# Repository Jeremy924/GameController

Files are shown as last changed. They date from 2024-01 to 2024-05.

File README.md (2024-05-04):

# Game Controller
User inputs are inputted into the arduino from two joysticks and four buttons. The arduino then sends the data to the computer through the serial port. 
The computer can also send a command to the arduino to set the color of an RGB LED. 

## Files
### GameController.py
The GameController class represents the game controller. The game controller class contains a
generator called start_input() that yields ControllerInput objects. The ControllerInput class represents the current
state of the controller inputs. The inputs are stored in a dictionary. The ControllerInput class
also has a dictionary containing only the inputs that have changed since last input. 

### KeyMapper.py
The KeyMapper class is used to simulate keyboard inputs based on user input from the game
controller. The KeyMapper class uses a dictionary from a json file to store the key
bindings. 

## PCB Design
Originally, a permanant breadboard was used, but the controller was switched to a PCB to make it sturdier. 
PCB Design

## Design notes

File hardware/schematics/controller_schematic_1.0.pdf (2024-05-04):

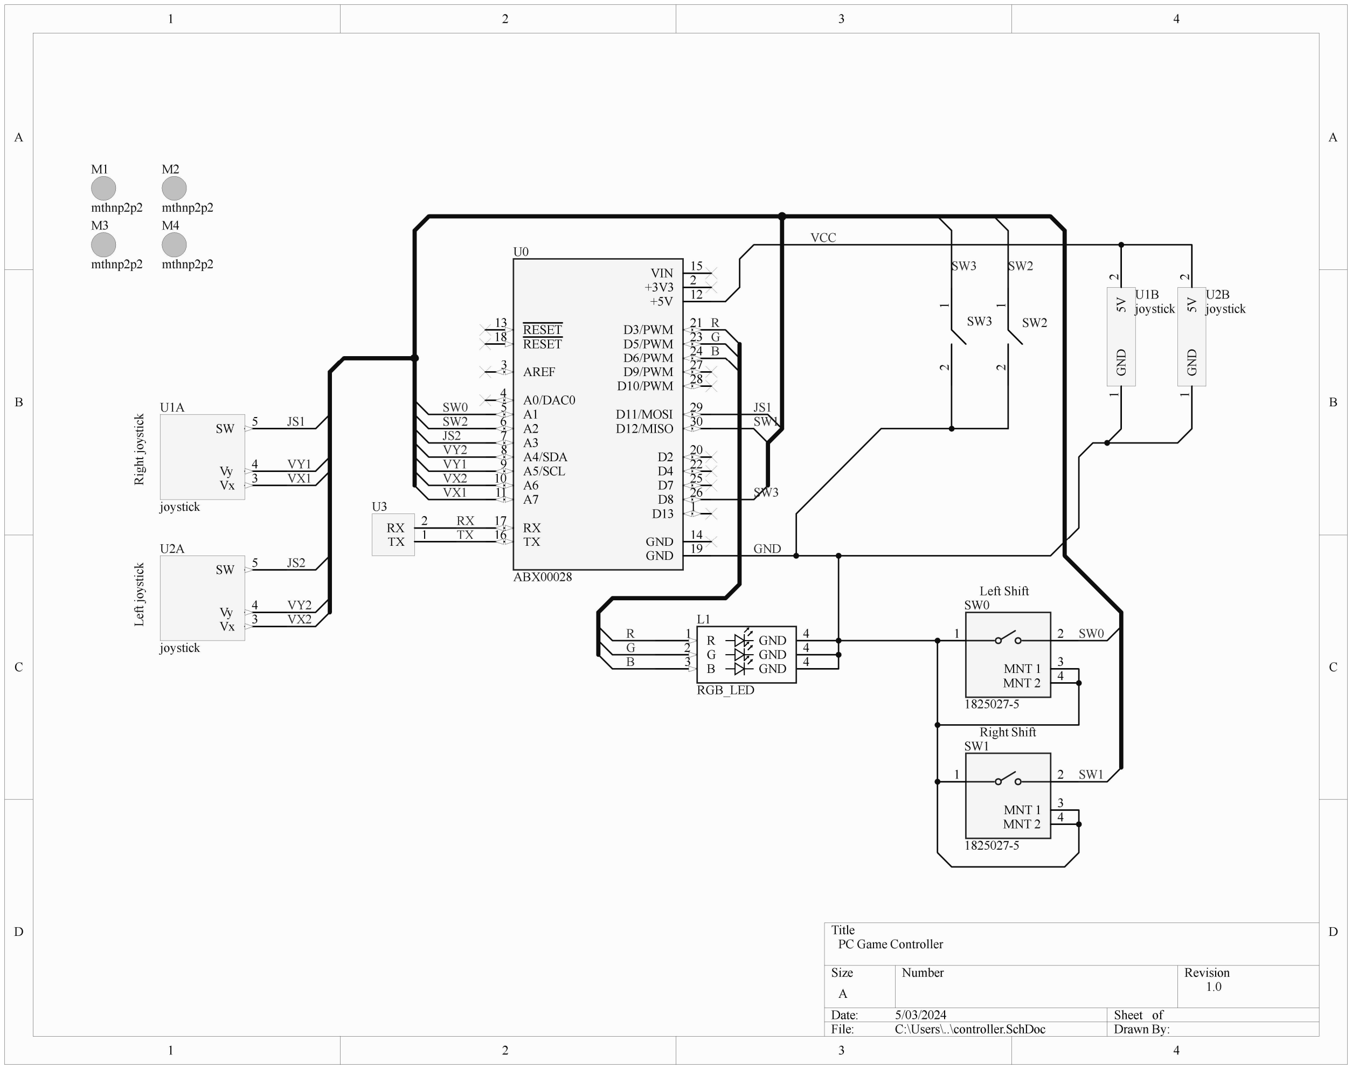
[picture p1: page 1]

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
Title

Size | Number | Revision
A
Date: | 5/03/2024 | Sheet of
File: | C:\Users\..\controller.SchDoc | Drawn By:

RESET 13
RESET 18

AREF 3

A0/DAC0 4
A1 5
A2 6
A3 7
A4/SDA 8
A5/SCL 9
A6 10
A7 11

RX 17
TX 16

VIN 15
+3V3 2
+5V 12

D3/PWM 21
D5/PWM 23
D6/PWM 24
D9/PWM 27
D10/PWM 28

D11/MOSI 29
D12/MISO 30

D2 20
D4 22
D7 25
D8 26
D13 1

GND 14
GND 19

U0

ABX00028

SW1

Right Shift

Left Shift Right joystick Left joystick

PC Game Controller

1.0

Vx 3

Vy 4

SW 5

U1A

joystick | 5V

## 2 GND

1

U1B
joystick

Vx 3

Vy 4

SW 5

U2A

joystick | 5V

## 2 GND

1

U2B
joystick
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
GND 4

GND 4

GND 4

L1

RGB_LED

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
SW3 SW2

JS1
SW1

SW3

GND

VCC

RX 2
TX 1

U3
RX
TX

1 2

SW2 ¹ 2
SW3

1 2

MNT 1 3
MNT 2 4

SW0

1825027-5

1 2

MNT 1 3
MNT 2 4

SW1

1825027-5

SW0

M1

mthnp2p2

M2

mthnp2p2
M3

mthnp2p2

M4

mthnp2p2

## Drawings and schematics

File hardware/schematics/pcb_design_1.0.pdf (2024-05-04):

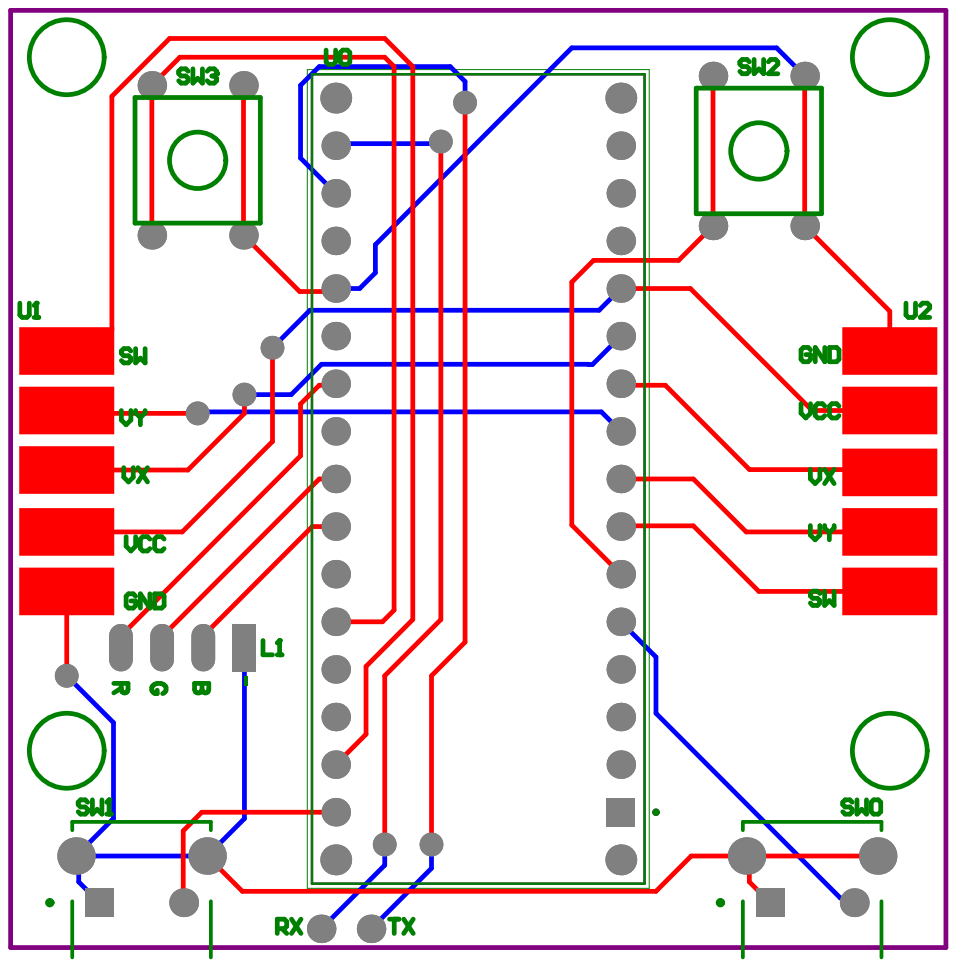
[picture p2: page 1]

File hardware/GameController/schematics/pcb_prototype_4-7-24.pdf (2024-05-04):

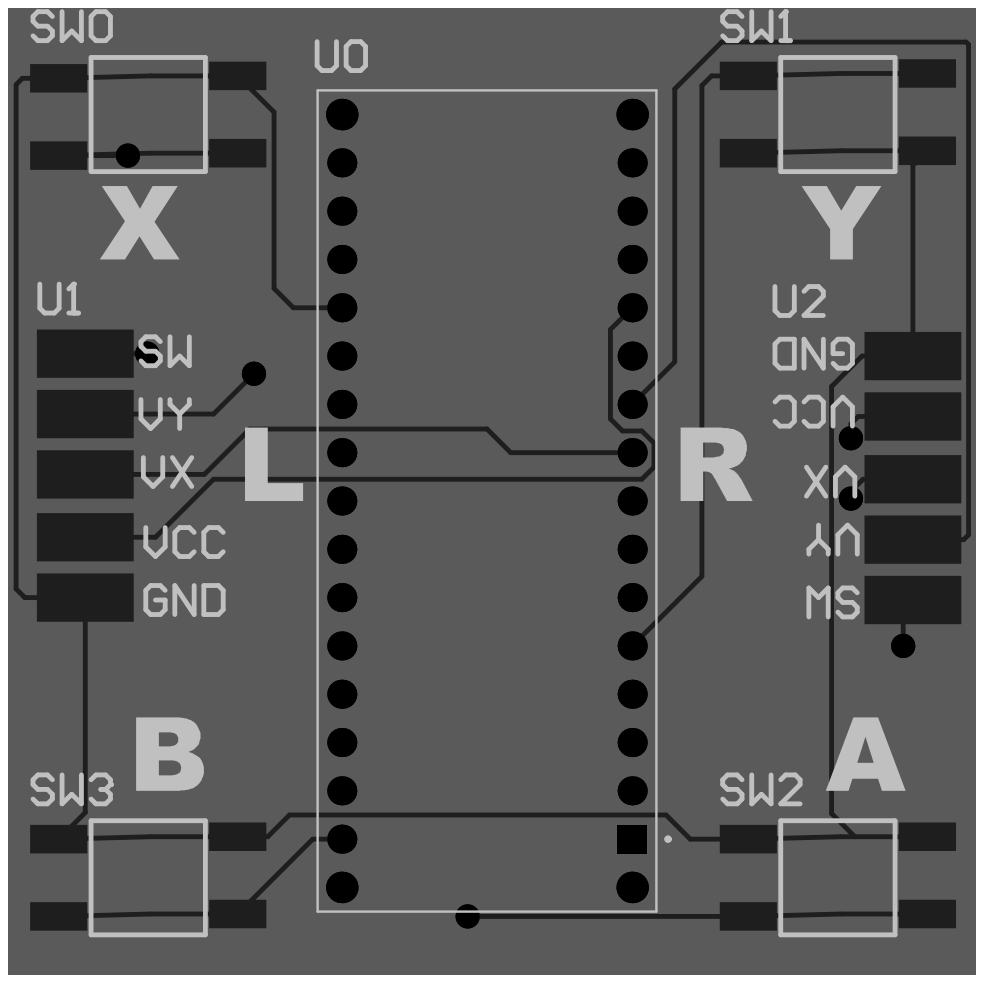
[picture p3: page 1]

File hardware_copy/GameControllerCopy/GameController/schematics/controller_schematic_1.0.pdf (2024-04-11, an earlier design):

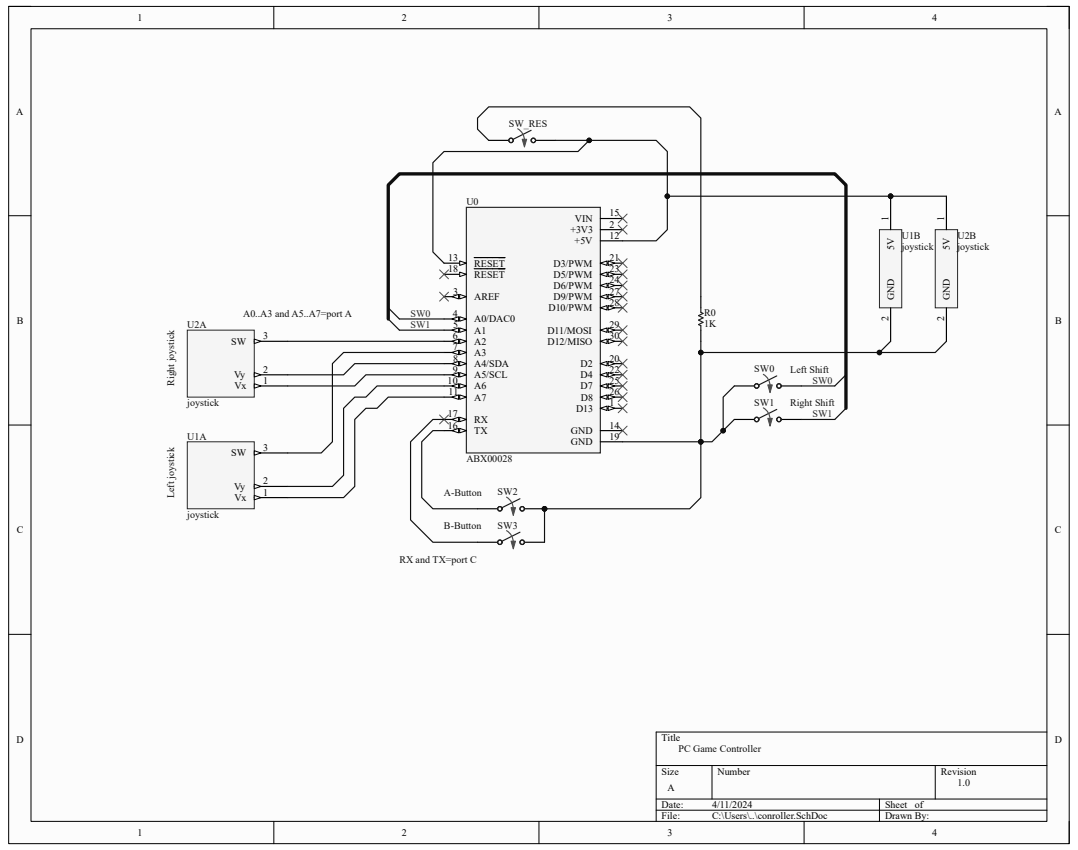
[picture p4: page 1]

joystick Right joystick Left joystick

RX and TX=port C

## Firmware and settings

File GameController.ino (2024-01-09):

#define RIGHT_BUTTON 6
#define LEFT_BUTTON 19

#define RIGHT_VRX A0
#define RIGHT_VRY A1
#define LEFT_VRX A2
#define LEFT_VRY A3

#define LEFT_JS_BUTTON A4
#define RIGHT_JS_BUTTON 4


#define RED 3
#define GREEN 9
#define BLUE 10

#define NUM_SENSORS 8

int lastVals[NUM_SENSORS] = { 0 };

bool isConnected = false;

void setup() {
  // put your setup code here, to run once:
  pinMode(LEFT_BUTTON, INPUT_PULLUP);
  pinMode(RIGHT_BUTTON, INPUT_PULLUP);
  pinMode(LEFT_JS_BUTTON, INPUT_PULLUP);
  pinMode(RIGHT_JS_BUTTON, INPUT_PULLUP);

  pinMode(RIGHT_VRX, INPUT);
  pinMode(LEFT_VRX, INPUT);

  pinMode(RIGHT_VRY, INPUT);
  pinMode(LEFT_VRY, INPUT);

  pinMode(RED, OUTPUT);
  pinMode(GREEN, OUTPUT);
  pinMode(BLUE, OUTPUT);

  Serial.begin(1000000);

  connect();
}

void connect() {
  if (isConnected) {
    return;
  }

  int count = 0;
  int colorVal = 10;
  bool forward = true;
  String s;
  do {
    while (!Serial.available()) {
    if (count % 50 == 0) if (forward) colorVal++; else colorVal--;
    if (forward) count++; else count--;
    if (count == 2000 || count == 0) forward = !forward;
    setLED(colorVal * 4, colorVal / 4, 0);
    delayMicroseconds(300);
    }
    s = Serial.readStringUntil('\n');
    

  } while (!s.equals("ready"));

  Serial.println("OK");

  while (Serial.available()) {
    Serial.read();
  }
  

  analogWrite(RED, 0);
  analogWrite(GREEN, 0);
  isConnected = true;
}

void setLED(byte red, byte green, byte blue) {
  if (red > 100) red = 100;
  if (green > 100) green = 100;
  if (blue > 100) blue = 100;
  analogWrite(RED, red);
  analogWrite(GREEN, green);
  analogWrite(BLUE, blue);
}

void checkForCommand() {
  if (Serial.available()) {
    String s = Serial.readStringUntil('\n');
    if (s == "LED") {
      while (!Serial.available()) continue;
      byte colors[3];
      Serial.readBytes(colors, 3);
      setLED(colors[0], colors[1], colors[2]);
    }
  }
}


void printState(int* values, int size) {
  checkForCommand();
  for (int i = 0; i < size; i++) {
    if (i < 2 || i == 4 || i == 5)
      Serial.println(values[i] >> 2);
    else
      Serial.println(values[i]);
  }

  Serial.println();
}


void outState(int* values, int size) {
  checkForCommand();
  Serial.write((byte) (values[0] >> 2)); // LEFT VRX
  Serial.write((byte) (values[1] >> 2)); // LEFT VRY
  Serial.write((byte) (values[4] >> 2)); // RIGHT VRX
  Serial.write((byte) (values[5] >> 2)); // RIGHT VRY

  //                       LEFT_BUTTON   LEFT_JS_BUTTON      RIGHT_BUTTON       RIGHT_JS_BUTTON
  byte combined_digitals = (values[2]) + (values[3] << 1) + (values[6] << 2) + (values[7] << 3);
  Serial.write(combined_digitals);
}


void loop() {
  int currentVals[] = { analogRead(LEFT_VRX), analogRead(LEFT_VRY), !digitalRead(LEFT_BUTTON), !digitalRead(LEFT_JS_BUTTON), 
                          analogRead(RIGHT_VRX), analogRead(RIGHT_VRY), !digitalRead(RIGHT_BUTTON), !digitalRead(RIGHT_JS_BUTTON) };

  for (int i = 0; i < NUM_SENSORS; i++) {
    if (currentVals[i] != lastVals[i]) {
      delay(1);
      outState(currentVals, NUM_SENSORS);
      break;
    }
  }

  for (int i = 0; i < NUM_SENSORS; i++) lastVals[i] = currentVals[i];

}

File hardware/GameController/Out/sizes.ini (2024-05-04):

[Page0.emf]
Pixel_PrintingWidth=6000
Pixel_PrintingHeight=4000
Mils_PrintingHeight=4000
Mils_PrintingWidth=6000

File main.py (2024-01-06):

import serial
import keyboard
import time
import sys

s = serial.Serial('COM7', 1_000_000)

gas = 0
brake = 0
turn_angle = 0
last = 502
value = None


def set_color(red, green, blue, port):
    b = bytearray(b'LED\n')
    b.append(red)
    b.append(green)
    b.append(blue)
    port.write(b)
    port.flush()
    time.sleep(0.01)


def unhandled_exception(exc_type, exc_value, exc_traceback):
    set_color(128, 0, 0, s)
    s.flush()
    raise exc_value


sys.excepthook = unhandled_exception


def buffered_read(port, sep=b'\r\n'):
    while True:
        port.write(b'ready\n')
        port.flush()
        time.sleep(0.1)

        if port.in_waiting != 0:
            val = port.read(4)
            if val == b'OK\r\n':
                break

    GAS_FLAG = 0x0002
    BRAKE_FLAG = 0x0001
    SHIFT_UP_FLAG = 0x0004
    SHIFT_DOWN_FLAG = 0x0008
    TURN_FLAG = 0xFFC0
    V_FLAG = 0xFF0000
    V_OFFSET = 16
    TURN_OFFSET = 6

    while True:
        buffer = port.read(3)
        byte_val = list(map(int, list(buffer)))
        value = (byte_val[2] << 16) + (byte_val[0] << 8) + byte_val[1]
        gas = value & GAS_FLAG != 0
        brake = value & BRAKE_FLAG != 0
        shift_up = value & SHIFT_UP_FLAG != 0
        shift_down = value & SHIFT_DOWN_FLAG != 0
        turn = (value & TURN_FLAG) >> TURN_OFFSET
        vertical = (value & V_FLAG) >> V_OFFSET
        yield gas, brake, shift_up, shift_down, (turn - 522), vertical


# 11000001

pulse_count = 0
last_movement = 0
last_shift_change = 0
gas_pressed = False
brake_pressed = False
left_turn_pressed = False
right_turn_pressed = False
shift_down_pressed = False
shift_up_pressed = False

for gas, brake, shift_up, shift_down, turn, vertical in buffered_read(s):
    gas = vertical < 100
    brake = vertical > 140

    if gas:
        if not gas_pressed:
            keyboard.press('w')
            gas_pressed = True
    else:
        if gas_pressed:
            keyboard.release('w')
            gas_pressed = False
    if brake:
        if not brake_pressed:
            keyboard.press('s')
            brake_pressed = True
    else:
        if brake_pressed:
            keyboard.release('s')
            brake_pressed = False

    if shift_up:
        if not shift_up_pressed:
            keyboard.press("'")
            shift_up_pressed = True
    else:
        if shift_up_pressed:
            keyboard.release("'")
            shift_up_pressed = False

    if shift_down:
        if not shift_down_pressed:
            shift_down_pressed = True
            keyboard.press('/')
    else:
        if shift_down_pressed:
            keyboard.release('/')
            shift_down_pressed = False

    if turn < -5:
        right_turn_pressed = False
        if last_movement == 1:
            pulse_count = 0
        last_movement = 2
        keyboard.release('a')
        if pulse_count == 0:
            if not left_turn_pressed:
                keyboard.press('d')
                left_turn_pressed = True
        elif pulse_count == 30:
            if left_turn_pressed:
                keyboard.release('d')
                left_turn_pressed = False
        pulse_count = (pulse_count + 1) % max(1, (50 + turn // 10))
    elif turn > 5:
        left_turn_pressed = False
        if last_movement == 2:
            pulse_count = 0
        last_movement = 1
        keyboard.release('d')
        if pulse_count == 0:
            if not right_turn_pressed:
                keyboard.press('a')
                right_turn_pressed = True
        elif pulse_count == 30:
            if right_turn_pressed:
                keyboard.release('a')
                right_turn_pressed = False
        pulse_count = (pulse_count + 1) % max(1, (50 - turn // 10))
    else:
        keyboard.release('d')
        keyboard.release('a')
        left_turn_pressed = False
        right_turn_pressed = False

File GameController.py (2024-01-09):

import serial
import time
import sys


class GameController:
    current_controller = None

    def __init__(self):
        self.port = serial.Serial('COM7', 1_000_000)
        self.analog_inputs = ['LEFT_VRX', 'LEFT_VRY', 'RIGHT_VRX', 'RIGHT_VRY']

    @classmethod
    def set_current_controller(cls, controller):
        cls.current_controller = controller

    @classmethod
    def get_current_controller(cls):
        return cls.current_controller

    def set_color(self, red, green, blue):
        set_color(red, green, blue, self.port)

    def start_input(self):
        port = self.port
        GameController.current_controller = self
        while True:
            port.write(b'ready\n')
            port.flush()
            time.sleep(0.1)

            if port.in_waiting != 0:
                val = port.read(4)
                if val == b'OK\r\n':
                    break

        LEFT_JS_BUTTON = 0x02
        RIGHT_BUTTON = 0x04
        RIGHT_JS_BUTTON = 0x08
        last_input = None

        while True:
            buffer = port.read(5)
            byte_val = list(map(int, list(buffer)))
            left_vrx = byte_val[0]
            left_vry = byte_val[1]
            right_vrx = byte_val[2]
            right_vry = byte_val[3]
            left_pressed = byte_val[4] & 1 == 1
            right_pressed = byte_val[4] & RIGHT_BUTTON != 0
            left_js_pressed = byte_val[4] & LEFT_JS_BUTTON != 0
            right_js_pressed = byte_val[4] & RIGHT_JS_BUTTON != 0

            last_input = ControllerInput(left_vrx, left_vry, right_vrx, right_vry, left_pressed, right_pressed,
                                         left_js_pressed, right_js_pressed, last_input)
            yield last_input


class ControllerInput:
    def __init__(self, left_vrx, left_vry, right_vrx, right_vry, left_pressed,
                 right_pressed, left_js_pressed, right_js_pressed, last):
        self.inputs = {'LEFT_VRX': left_vrx, 'LEFT_VRY': left_vry, 'RIGHT_VRX': right_vrx, 'RIGHT_VRY': right_vry,
                       'LEFT_BUTTON': left_pressed, 'RIGHT_BUTTON': right_pressed, 'LEFT_JS_BUTTON': left_js_pressed,
                       'RIGHT_JS_BUTTON': right_js_pressed}
        self.analog_inputs = ['LEFT_VRX', 'LEFT_VRY', 'RIGHT_VRX', 'RIGHT_VRY']
        self.last = last
        self.changes = {}
        for key in self.inputs:
            if (last is None or self.inputs[key] != last.inputs[
                key] and key not in self.analog_inputs or key in self.analog_inputs
                    and abs(self.inputs[key] - last.inputs[key]) > 0):
                self.changes[key] = self.inputs[key]

    def __str__(self):
        return str(self.changes)


def set_color(red, green, blue, port):
    b = bytearray(b'LED\n')
    b.append(red)
    b.append(green)
    b.append(blue)
    port.write(b)
    port.flush()


def unhandled_exception(exc_type, exc_value, exc_traceback):
    if GameController.current_controller is None:
        raise exc_value

    if GameController.current_controller is not None:
        GameController.current_controller.set_color(128, 0, 0)
        GameController.current_controller.port.flush()
    raise exc_value


sys.excepthook = unhandled_exception

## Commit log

2024-01-06 added arduino code
2024-01-09 added pwm, fixed other issues
    [GameController.py, KeyMapper.py]
2024-01-13 working on schematic
    [GameController.kicad_pcb, GameController.kicad_sch]
2024-04-10 added schematic
    [GameController.PrjPcb, conroller.SchDoc, joystick.SchLib]
2024-04-11 worked on schematic
    [conroller.SchDoc]
2024-05-04 finished PCB design
    [GameController.PrjPcb, RGB_LED.PcbLib, RGB_LED.SchLib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]
2024-05-04 added pdfs of schematic
    [controller.SchDoc]
2024-05-04 made it symmetrical again
    [controller.PcbDoc]
